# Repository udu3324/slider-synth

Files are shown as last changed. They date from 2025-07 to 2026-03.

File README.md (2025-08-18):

# Slider Synth



A synth that uses a linear touch sensor with a force sensor underneath to create cool sounds. It is inspired by the modulin by wintergatan. Powered by the esp32-s3 and mozzi library.

## Purpose

I built this pcb to make my diy setup more professional. I originally hooked everything up with an arduino but was really hard to cary around without dropping the breadboard or unplugging something. This design leaves it hot pluggable as well as super professional and more polished. 

## Schematic

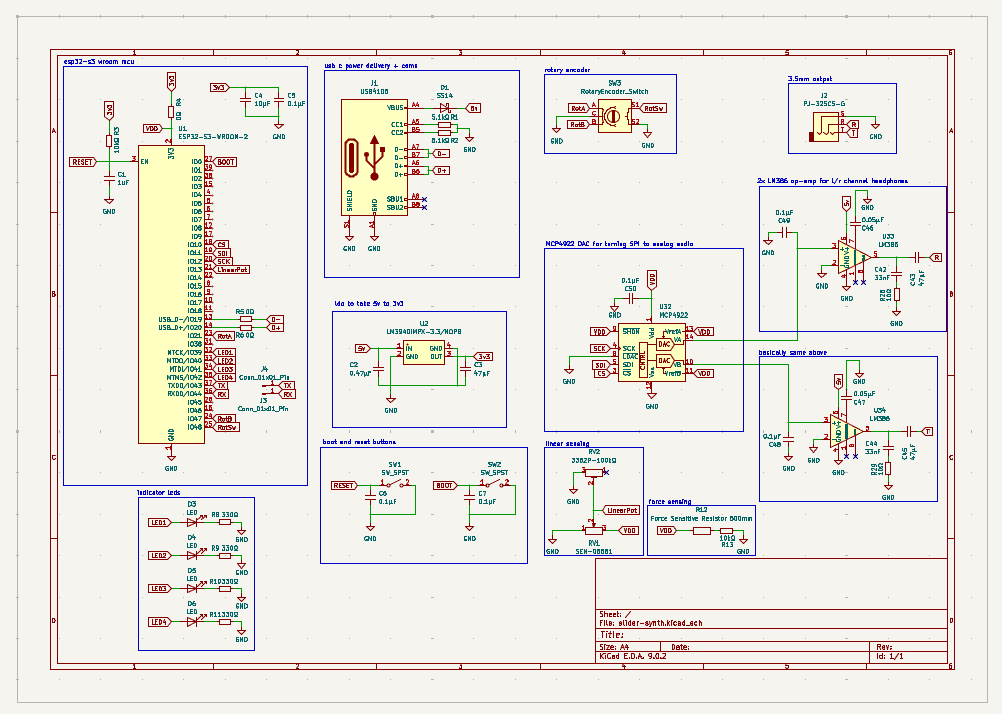
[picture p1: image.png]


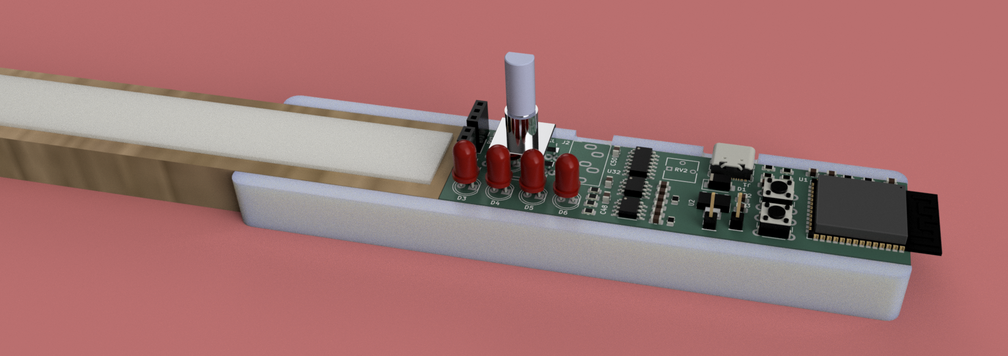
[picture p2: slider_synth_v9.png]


## Additional Notes

[rotary encoder model](https://github.com/KiCad/kicad-packages3D/issues/547)

[sot-223 model](https://grabcad.com/library/discrete-smd-1/details?folder_id=1300113)

## BOM

I am supplying my own esp32-s3, rotary encoder, buttons, leds, and some other stuff that would cause the price to spike up to $30

I also have the linear softpot potentiometer, force sensitive resistor, and plywood strip on hand. **They total about $50** (plywood was scrap/free)

**Before fabricating the pcb, make sure the traces for the FSR is going to IO4 and not IO38!!!**

| Price  | Part Number | Type | LCSC Part | Owner | Designators | Qty | Manufacturer |
|:---|:---|:---|:---|:---|:---|---:|:---|
| $0.02  | CL21A106KAYNNNE | Basic | C15850 | System | C4 | 2 | JLCPCB |
| $0.17  | CL21A476MQYNNNE | Basic | C16780 | System | C3,C43,C45 | 6 | JLCPCB |
| $0.03  | SS14 | Basic | C2480 | System | D1 | 2 | JLCPCB |
| $0.02  | CL21B105KBFNNNE | Basic | C28323 | System | C1 | 2 | JLCPCB |
| $2.11  | LM3940IMPX-3.3/NOPB | Extended | C544820 | System | U2 | 2 | JLCPCB |
| $0.05  | CC0805KRX7R9BB104 | Basic | C49678 | System | C48,C49,C5,C50,C6,C7 | 12 | JLCPCB |
| $0.37  | LM386 | Extended | C5157706 | System | U33,U34 | 4 | JLCPCB |
| $0.03  | CL21B474KBFNNNE | Basic | C13967 | System | C2 | 2 | JLCPCB |
| $0.01  | 0805W8F0000T5E | Basic | C17477 | System | R4,R5,R6 | 6 | JLCPCB |
| $5.35  | MCP4922-E/SL | Extended | C39851 | System | U32 | 2 | JLCPCB |
| $0.01  | 0805W8F1002T5E | Basic | C17414 | System | R13,R3 | 4 | JLCPCB |
| $0.01  | 0805W8F100JT5E | Basic | C17415 | System | R28,R29 | 4 | JLCPCB |
| $2.24  | USB4105-GF-A-120 | Extended | C5184243 | System | J1 | 2 | JLCPCB |
| $0.03  | 0805B333K500NT | Basic | C1739 | System | C42,C44 | 4 | JLCPCB |
| $0.01  | 0805W8F3300T5E | Basic | C17630 | System | R10,R11,R8,R9 | 8 | JLCPCB |
| $0.05  | CL21B473KBCNNNC | Basic | C53134 | Customer | C46,C47 | 4 | JLCPCB |
| $0.01  | 0805W8F5101T5E | Basic | C27834 | System | R1,R2 | 4 | JLCPCB |
| $23.28 | **Total Part Price** | | | | | | |
| | | | | | | | |
| $37.24 | Merchandise Total | | | | | | |
| $26.56 | Shipping Estimate | | | | | | |
| $5.27  | Sales Tax | | | | | | |
| $20.49 | Customs duties & taxes | | | | | | |
| $89.56 | **Grand Total** | | | | | | |

Actual total would be around ~$150 USD including my own components sourced.

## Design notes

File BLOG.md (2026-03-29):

# Post Fabrication Results and Testing

After soldering everything and writing firmware to the slider-synth, there were a couple issues that lowered its quality in general.

At first, one of the sensors did not work at all because I accidentally used a gpio that didn't support analog input. I solved this by soldering a jumper wire which sticks out a little bit, but could easily be fixed for a second round of pcbs.         
           

The audio output kind of sucks. Although it does give a nice harsh analog sound, it is really irritating and no code can fix it due to the passives/ics I used for audio out. I could definitely retry a better design.          
   
     

Plus, i was a little confused and the library i use for digital signal processing (mozzi) specified something else different for my audio. I was trying to implement its [hi-fi audio](https://sensorium.github.io/Mozzi/learn/output/) but accidentally muted the right channel making it a mono output

The PCB also lacks some real mounting holes for more professional case/mounts, and the press fit design sometimes fails due to force from the controls


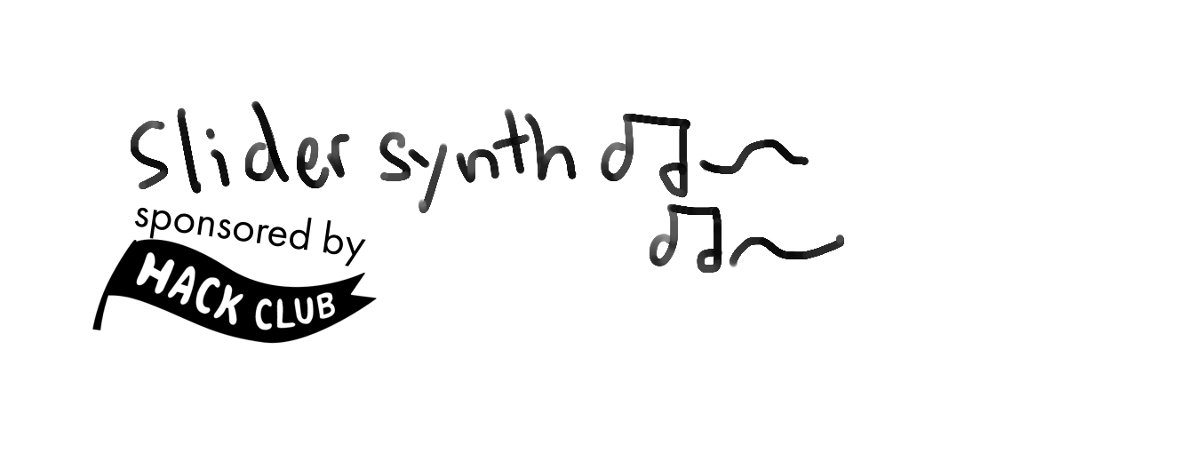
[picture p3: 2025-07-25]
assets/slider-synth-Edge_Cuts.png

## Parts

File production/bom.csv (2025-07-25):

Designator | Footprint | Quantity | Value | LCSC Part #
C1 | 0805 | 1 | 1uF
C2 | 0805 | 1 | 0.47μF
C3, C43, C45 | 0805 | 3 | 47μF
C4 | 0805 | 1 | 10μF
C42, C44 | 0805 | 2 | 33nF
C46, C47 | 0805 | 2 | 0.05μF
C48, C49, C5, C50, C6, C7 | 0805 | 6 | 0.1μF
D1 | D_SMA | 1 | SS14
D3, D4, D5, D6 | LED_D5.0mm | 4 | LED
J1 | USB_C_Receptacle_GCT_USB4105-xx-A_16P_TopMnt_Horizontal | 1 | USB4105
J2 | Jack_3.5mm_CUI_SJ1-3535NG_Horizontal | 1 | PJ-325C5-G | C692438
J3, J4 | PinHeader_1x01_P2.54mm_Vertical | 2 | Conn_01x01_Pin
R1, R2 | 0805 | 2 | 5.1kΩ
R10, R11, R8, R9 | 0805 | 4 | 330Ω
R12 | PinSocket_1x02_P2.54mm_Vertical | 1 | Force Sensitive Resistor 500mm
R13, R3 | 0805 | 2 | 10kΩ
R28, R29 | 0805 | 2 | 10Ω
R4, R5, R6 | 0805 | 3 | 0Ω
RV1 | PinSocket_1x03_P2.54mm_Vertical | 1 | SEN-08681
RV2 | POT_3362P | 1 | 3362P-100kΩ
SW1, SW2 | SW_PUSH_6mm | 2 | SW_SPST
SW3 | RotaryEncoder_Alps_EC11E-Switch_Vertical_H20mm | 1 | RotaryEncoder_Switch
U1 | ESP32-S3-WROOM-2 | 1 | ESP32-S3-WROOM-2
U2 | SOT-223-4_L6.5-W3.5-P2.30-LS7.0-BR | 1 | LM3940IMPX-3.3/NOPB | C544820
U32 | SOIC-14_3.9x8.7mm_P1.27mm | 1 | MCP4922
U33, U34 | SOIC-8_3.9x4.9mm_P1.27mm | 2 | LM386

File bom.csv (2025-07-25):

Part Number | Type | LCSC Part | Owner | Designators | Qty | Manufacturer | Price
CL21A106KAYNNNE | Basic | C15850 | System | C4 | 2 | JLCPCB | $0.02
CL21A476MQYNNNE | Basic | C16780 | System | C3,C43,C45 | 6 | JLCPCB | $0.17
SS14 | Basic | C2480 | System | D1 | 2 | JLCPCB | $0.03
CL21B105KBFNNNE | Basic | C28323 | System | C1 | 2 | JLCPCB | $0.02
LM3940IMPX-3.3/NOPB | Extended | C544820 | System | U2 | 2 | JLCPCB | $2.11
CC0805KRX7R9BB104 | Basic | C49678 | System | C48,C49,C5,C50,C6,C7 | 12 | JLCPCB | $0.05
LM386 | Extended | C5157706 | System | U33,U34 | 4 | JLCPCB | $0.37
CL21B474KBFNNNE | Basic | C13967 | System | C2 | 2 | JLCPCB | $0.03
0805W8F0000T5E | Basic | C17477 | System | R4,R5,R6 | 6 | JLCPCB | $0.01
MCP4922-E/SL | Extended | C39851 | System | U32 | 2 | JLCPCB | $5.35
0805W8F1002T5E | Basic | C17414 | System | R13,R3 | 4 | JLCPCB | $0.01
0805W8F100JT5E | Basic | C17415 | System | R28,R29 | 4 | JLCPCB | $0.01
USB4105-GF-A-120 | Extended | C5184243 | System | J1 | 2 | JLCPCB | $2.24
0805B333K500NT | Basic | C1739 | System | C42,C44 | 4 | JLCPCB | $0.03
0805W8F3300T5E | Basic | C17630 | System | R10,R11,R8,R9 | 8 | JLCPCB | $0.01
CL21B473KBCNNNC | Basic | C53134 | Customer | C46,C47 | 4 | JLCPCB | $0.05
0805W8F5101T5E | Basic | C27834 | System | R1,R2 | 4 | JLCPCB | $0.01

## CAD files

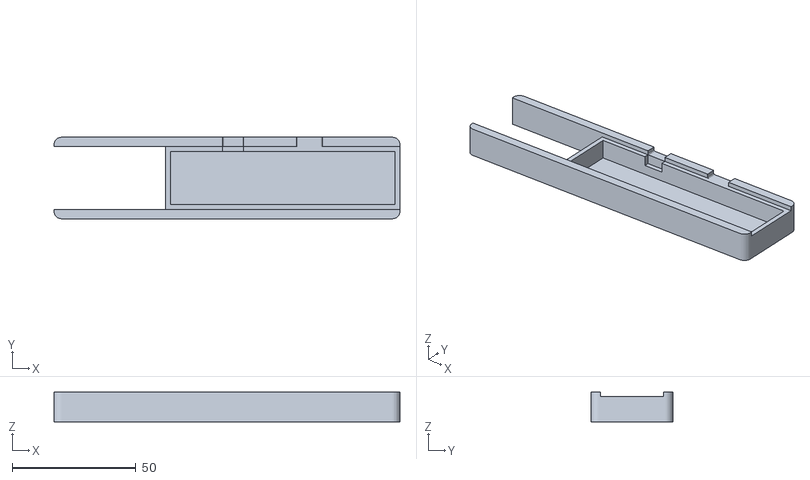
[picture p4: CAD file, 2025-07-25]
cad/Case.stl
140.0 x 33.0 x 12.0

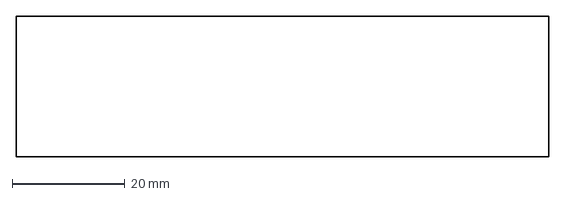
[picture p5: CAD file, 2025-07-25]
pcb/pcb edge cut.dxf
94.5 x 25.0 mm

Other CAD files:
cad/slider synth v7.f3d

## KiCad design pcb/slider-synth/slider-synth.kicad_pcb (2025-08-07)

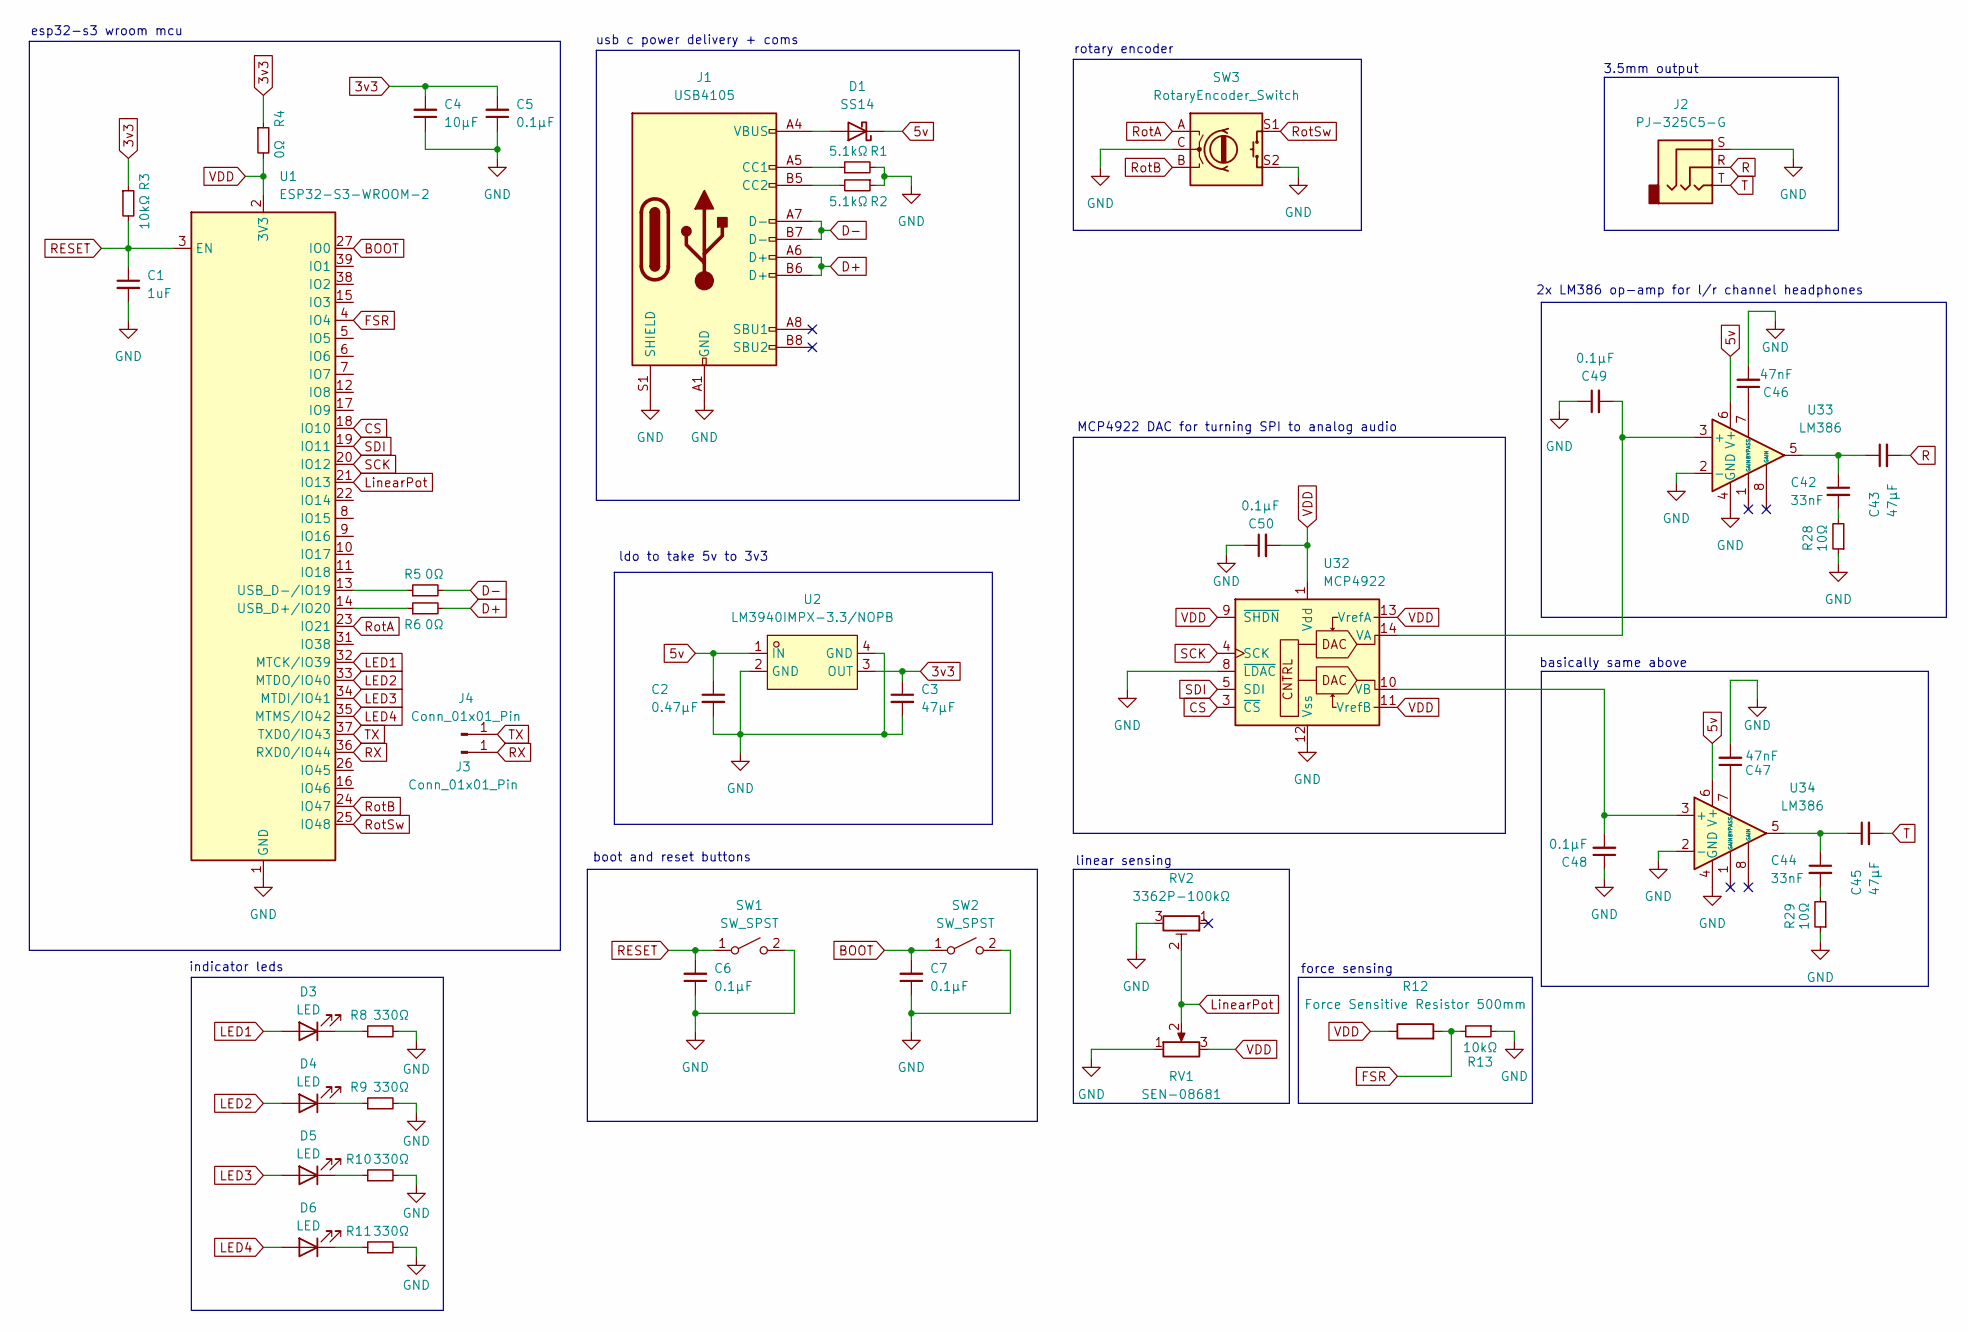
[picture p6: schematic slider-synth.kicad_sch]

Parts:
C1: 1uF; C_0805_2012Metric
C2: 0.47μF; C_0805_2012Metric
C3, C43, C45: 47μF; C_0805_2012Metric
C4: 10μF; C_0805_2012Metric
C5, C6, C7, C48, C49, C50: 0.1μF; C_0805_2012Metric
C42, C44: 33nF; C_0805_2012Metric
C46, C47: 47nF; C_0805_2012Metric
D1: SS14; D_SMA
D3, D4, D5, D6: LED; LED_D5.0mm
J1: USB4105; USB_C_Receptacle_GCT_USB4105-xx-A_16P_TopMnt_Horizontal
J2: PJ-325C5-G; Jack_3.5mm_CUI_SJ1-3535NG_Horizontal; LCSC C692438
J3, J4: Conn_01x01_Pin; PinHeader_1x01_P2.54mm_Vertical
R1, R2: 5.1kΩ; R_0805_2012Metric
R3, R13: 10kΩ; R_0805_2012Metric
R4, R5, R6: 0Ω; R_0805_2012Metric
R8, R9, R10, R11: 330Ω; R_0805_2012Metric
R12: Force Sensitive Resistor 500mm; PinSocket_1x02_P2.54mm_Vertical
R28, R29: 10Ω; R_0805_2012Metric
RV1: SEN-08681; PinSocket_1x03_P2.54mm_Vertical
RV2: 3362P-100kΩ; POT_3362P
SW1, SW2: SW_SPST; SW_PUSH_6mm
SW3: RotaryEncoder_Switch; RotaryEncoder_Alps_EC11E-Switch_Vertical_H20mm
U1: ESP32-S3-WROOM-2
U2: LM3940IMPX-3.3/NOPB; SOT-223-4_L6.5-W3.5-P2.30-LS7.0-BR; LCSC Part C544820
U32: MCP4922; SOIC-14_3.9x8.7mm_P1.27mm
U33, U34: LM386; SOIC-8_3.9x4.9mm_P1.27mm

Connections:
3v3: C3.1, C4.2, C5.2, R3.1, R4.1, U2.3 (OUT)
5v: C2.1, D1.1 (K), U2.1 (IN), U33.6 (V+), U34.6 (V+)
BOOT: C7.2, SW2.1 (A), U1.27 (IO0)
CS: U1.18 (IO10), U32.3 (~CS)
D+: J1.A6 (D+), J1.B6 (D+), R6.2
D-: J1.A7 (D-), J1.B7 (D-), R5.2
FSR: R12.2, R13.2, U1.4 (IO4)
GND: C1.2, C2.2, C3.2, C4.1, C5.1, C6.1, C7.1, C46.2, C47.2, C48.1, C49.1, C50.1, J1.A1 (GND), J1.A12 (GND), J1.B1 (GND), J1.B12 (GND), J1.S1 (SHIELD), J2.S, R1.2, R2.1, R8.2, R9.2, R10.2, R11.2, R13.1, R28.1, R29.1, RV1.1, RV2.3, SW1.2 (B), SW2.2 (B), SW3.C, SW3.S2, U1.1 (GND), U1.40 (GND), U1.41 (GND), U2.2 (GND), U2.4 (GND), U32.8 (~LDAC), U32.12 (Vss), U33.2 (-), U33.4 (GND), U34.2 (-), U34.4 (GND)
LED1: D3.2 (A), U1.32 (MTCK/IO39)
LED2: D4.2 (A), U1.33 (MTDO/IO40)
LED3: D5.2 (A), U1.34 (MTDI/IO41)
LED4: D6.2 (A), U1.35 (MTMS/IO42)
LinearPot: RV1.2, RV2.2, U1.21 (IO13)
unnamed: C42.1, C43.1, U33.5
unnamed: C42.2, R28.2
unnamed: C44.1, C45.1, U34.5
unnamed: C44.2, R29.2
unnamed: D1.2 (A), J1.A4 (VBUS), J1.A9 (VBUS), J1.B4 (VBUS), J1.B9 (VBUS)
unnamed: D3.1 (K), R8.1
unnamed: D4.1 (K), R9.1
unnamed: D5.1 (K), R10.1
unnamed: D6.1 (K), R11.1
unnamed: J1.A5 (CC1), R1.1
unnamed: J1.B5 (CC2), R2.2
unnamed: R6.1, U1.14 (USB_D+/IO20)
unnamed: R5.1, U1.13 (USB_D-/IO19)
unnamed: C49.2, U32.14 (VA), U33.3 (+)
unnamed: C48.2, U32.10 (VB), U34.3 (+)
unnamed: C46.1, U33.7 (BYPASS)
unnamed: C47.1, U34.7 (BYPASS)
R: C43.2, J2.R
RESET: C1.1, C6.2, R3.2, SW1.1 (A), U1.3 (EN)
RX: J3.1, U1.36 (RXD0/IO44)
RotA: SW3.A, U1.23 (IO21)
RotB: SW3.B, U1.24 (IO47)
RotSw: SW3.S1, U1.25 (IO48)
SCK: U1.20 (IO12), U32.4 (SCK)
SDI: U1.19 (IO11), U32.5 (SDI)
T: C45.2, J2.T
TX: J4.1, U1.37 (TXD0/IO43)
VDD: C50.2, R4.2, R12.1, RV1.3, U1.2 (3V3), U32.1 (Vdd), U32.9 (~SHDN), U32.11 (VrefB), U32.13 (VrefA)

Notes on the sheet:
esp32-s3 wroom mcu
MCP4922 DAC for turning SPI to analog audio
3.5mm output
force sensing
basically same above
rotary encoder
usb c power delivery + coms
ldo to take 5v to 3v3
2x LM386 op-amp for l/r channel headphones
boot and reset buttons
indicator leds
linear sensing

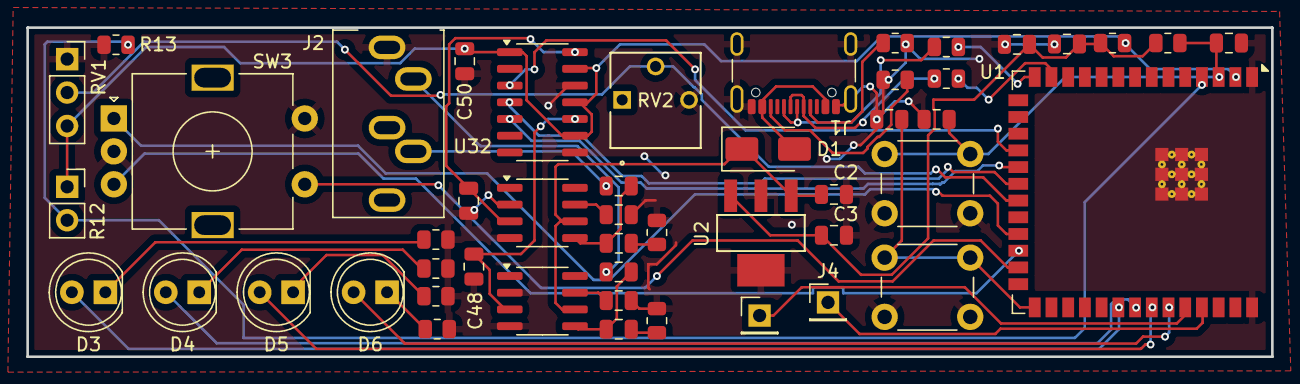
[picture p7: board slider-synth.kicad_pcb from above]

Board: 2 copper layers, 94.6 x 25.0 mm, 49 parts (0 on the bottom side), 41 nets.

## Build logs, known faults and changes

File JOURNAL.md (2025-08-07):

---
title: "slider synth"
author: "@Danny"
description: "A esp32 based synth that uses a touch pot and fsr."
created_at: "2025-07-23"
---

**Total time take: 15 hours**

# June 23rd: Planning + Schematic



I used some of my own references as well as these ones below. I was able to setup a lot of essential features like usb c flashing, 5v to 3v3, uart, and boot/reset buttons.
* [devkit schematics](https://dl.espressif.com/dl/schematics/SCH_ESP32-S3-DevKitC-1_V1.1_20220413.pdf)
* [esp32-s3-wroom datasheet](https://www.espressif.com/sites/default/files/documentation/esp32-s3-wroom-1_wroom-1u_datasheet_en.pdf)
* [user guide](https://docs.espressif.com/projects/esp-dev-kits/en/latest/esp32s3/esp32-s3-devkitc-1/user_guide_v1.1.html)

**Total time spent: ~4 hours**

# June 24th: Adding more features



I finished all of the audio circuit above and added more features like led indicators and a rotary encoder for extra control.



**Total time spent: ~6 hours**

# June 25th: Placement, Routing, CAD, and everything else



For placement, I had a solid plan of selecting an entire box/feature in my schematic and seperating that to then place.

After everything was placed, I can finally route and rotate any components if needed for better routing.



I made a simple case that would press fit onto my plywood strip and pcb. I wanted it to be flush with the thickness of the plywood to not add any extra height.

**Total time spent: ~5 hours**

# MILESTONE: MY PROJECT WAS APPROVED!!!!

Time to wait for the grant and everything to be shipped.

**Total time spent: ~0 hours**

# August 4th: PCB Assembly



My pcbs arrived! I chose to not to include some parts as it would cost more to assemble. I have some on hand already, like the esp32-s3-wroom.



I also did not order a stencil, so I had to manually apply and shape the solder paste to each pad. It was okay.

**Total time spent: ~4 hours**

# August 5th: Finished Assembly, now Debugging





I am so glad I connected my UART to these headers for debugging on my oscilliscope. For some reason, I can't get platformio to read any serial.



I am so stupid. I did not check if the pinout i chose for my force sensitive resistor supported adc. (IO38) I had to solder a jumper wire to fix this issue.

Moving onto the code part, something is not right. I am using mozzi which is a dsp library for synths. For some reason, it either outputs nothing or strange frequencies. Hopefully its not my schematic that is wrong.

**Total time spent: ~6 hours**

# August 6th: Finished!!!



I found out the original reason why my synth sounded strange. It was because i was calculating my hz wrong for my scale, as the numbers were very large/wrong.

I put four leds and a encoder with a button to cycle through modes that modify the synth's sound.

After making sure everything was programmed right with little bugs left, it sounded neat and has tons of possibilities now.

**Total time spent: ~4 hours**

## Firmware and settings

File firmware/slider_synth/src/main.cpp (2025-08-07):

#include "MozziConfigValues.h"  // for named option values

#define MOZZI_AUDIO_MODE MOZZI_OUTPUT_EXTERNAL_TIMED
#define MOZZI_AUDIO_BITS 24
#define MOZZI_CONTROL_RATE 256 // Hz, powers of 2 are most reliable

#include <Mozzi.h>
#include <Oscil.h>
#include <tables/sin2048_int8.h> // table for Oscils to play

#include <SPI.h>
#include <DAC_MCP49xx.h>  // https://github.com/tomcombriat/DAC_MCP49XX 
// which is an adapted fork from https://github.com/exscape/electronics/tree/master/Arduino/Libraries/DAC_MCP49xx  (Thomas Backman)
#include <ESP32Encoder.h>
#include <Ticker.h>

#define Linear_Pot_Pin 13 // Linear Potentiometer
#define FSR_Pin 4 // Force Sensitive Resistor

#define LED0_Pin 39
#define LED1_Pin 40
#define LED2_Pin 41
#define LED3_Pin 42

#define TX_Pin 43
#define RX_Pin 44

#define Rotary_A_Pin 21
#define Rotary_B_Pin 47
#define Rotary_Button_Pin 48

#define SPI_SCK   12  // SCK (Clock)
#define SPI_MOSI  11  // SDI (MOSI)
#define SPI_MISO  9   // SDO (MISO) UNUSED, NOT ON THE MCP4922
// External audio output parameters and DAC declaration
#define SS_PIN 10  // if you are on AVR and using PortWrite you need still need to put the pin you are actually using: 7 on Uno, 38 on Mega
#define BITS_PER_CHANNEL 12  // each channel of the DAC is outputting 12 bits

const int fsr_vel_start = 18000;
const int fsr_velocity_limit = 56688;

int starting_octave = 3; //cant be less than 0
const int scale = 3; //scale of octaves playable

int pitch; //27.5hz-4186hz
int velocity; //0-127

const float base_freq = 32.703; // C1
float hz_map_low;
float hz_map_high;

float depth = 0.02;

//not me
const float depth_min = 0.0;
const float depth_max = 0.2;
const float depth_step = 0.01;

float vibrato_speed = 6.5;
const float vibrato_speed_min = 1.0;
const float vibrato_speed_max = 15.0;
const float vibrato_speed_step = 0.5;

float filter_cutoff = 1.0;
const float filter_cutoff_min = 0.1;
const float filter_cutoff_max = 2.0;
const float filter_cutoff_step = 0.1;
//not me above

int mode = 0;
int changing_to = 0;
bool changing_mode = false;

// Synthesis part
Oscil <SIN2048_NUM_CELLS, MOZZI_AUDIO_RATE> aSin(SIN2048_DATA);
Oscil <2048, MOZZI_CONTROL_RATE> kVib(SIN2048_DATA);

DAC_MCP49xx dac(DAC_MCP49xx::MCP4922, SS_PIN);

ESP32Encoder encoder;

int linear_val;
int force_val;
int encoder_count = 0;
bool slow_down = false;

void ledModeFlash();

Ticker ledModeFlashTimer(ledModeFlash, 100);

void ledModeFlash() {

  digitalWrite(LED0_Pin, LOW);
  digitalWrite(LED1_Pin, LOW);
  digitalWrite(LED2_Pin, LOW);
  digitalWrite(LED3_Pin, LOW);

  if (changing_mode) {
    switch (changing_to) {
      case 0:
        digitalWrite(LED0_Pin, !digitalRead(LED0_Pin));
        break;
      case 1:
        digitalWrite(LED1_Pin, !digitalRead(LED1_Pin));
        break;
      case 2:
        digitalWrite(LED2_Pin, !digitalRead(LED2_Pin));
        break;
      case 3:
        digitalWrite(LED3_Pin, !digitalRead(LED3_Pin));
        break;
    }
  } else {
    switch (mode) {
      case 0:
        digitalWrite(LED0_Pin, HIGH);
        break;
      case 1:
        digitalWrite(LED1_Pin, HIGH);
        break;
      case 2:
        digitalWrite(LED2_Pin, HIGH);
        break;
      case 3:
        digitalWrite(LED3_Pin, HIGH);
        break;
    }
  }
}

void buttonSlowDown();

Ticker slowDownTimer(buttonSlowDown, 1000);

void buttonSlowDown() {
  slow_down = false;
}

void generateHz() {
  hz_map_low = base_freq * pow(2, starting_octave - 1);
  hz_map_high = hz_map_low * pow(2, scale);
}

void octaveUp() {
  if (starting_octave >= 8) return;

  starting_octave++;
  generateHz();
}

void octaveDown() {
  if (starting_octave <= -2) return;

  starting_octave--;
  generateHz();
}

void vibratoUp() {
  if (depth >= depth_max) return;
  
  depth += depth_step;
  if (depth > depth_max) depth = depth_max;
}

void vibratoDown() {
  if (depth <= depth_min) return;
  
  depth -= depth_step;
  if (depth < depth_min) depth = depth_min;
}

void vibratoSpeedUp() {
  if (vibrato_speed >= vibrato_speed_max) return;
  
  vibrato_speed += vibrato_speed_step;
  if (vibrato_speed > vibrato_speed_max) vibrato_speed = vibrato_speed_max;
  
  kVib.setFreq(vibrato_speed);
}

void vibratoSpeedDown() {
  if (vibrato_speed <= vibrato_speed_min) return;
  
  vibrato_speed -= vibrato_speed_step;
  if (vibrato_speed < vibrato_speed_min) vibrato_speed = vibrato_speed_min;
  
  kVib.setFreq(vibrato_speed);
}

void filterUp() {
  if (filter_cutoff >= filter_cutoff_max) return;
  
  filter_cutoff += filter_cutoff_step;
  if (filter_cutoff > filter_cutoff_max) filter_cutoff = filter_cutoff_max;
}

void filterDown() {
  if (filter_cutoff <= filter_cutoff_min) return;
  
  filter_cutoff -= filter_cutoff_step;
  if (filter_cutoff < filter_cutoff_min) filter_cutoff = filter_cutoff_min;
}

void runEncoderModeUp() {
  switch (mode) {
    case 0:
      octaveUp();
      break;
    case 1:
      vibratoUp();
      break;
    case 2:
      vibratoSpeedUp();
      break;
    case 3:
      filterUp();
      break;
  }
}

void runEncoderModeDown() {
  switch (mode) {
    case 0:
      octaveDown();
      break;
    case 1:
      vibratoDown();
      break;
    case 2:
      vibratoSpeedDown();
      break;
    case 3:
      filterDown();
      break;
  }
}

void audioOutput(const AudioOutput f) // f is a structure containing both channels
{

  int out = MOZZI_AUDIO_BIAS + f.l();

  unsigned short lowBits = (unsigned short) out;  //
  unsigned short highBits =  out >> BITS_PER_CHANNEL;

  dac.output2(highBits, lowBits);  // outputs the two channels in one call.
}

void setup() {
  // serial for uart
  Serial.begin(115200, SERIAL_8N1, RX, TX);

  Serial.println("udu3324 was here!!");

  // Set custom SPI pins
  SPI.begin(SPI_SCK, SPI_MISO, SPI_MOSI);

  dac.init();   // start SPI communications
  //dac.setPortWrite(true);  //comment this line if you do not want to use PortWrite (for non-AVR platforms)
  
  //calculate the starting hz
  generateHz();

  //vibrato setup
  kVib.setFreq(vibrato_speed);

  pinMode(LED0_Pin, OUTPUT);
  pinMode(LED1_Pin, OUTPUT);
  pinMode(LED2_Pin, OUTPUT);
  pinMode(LED3_Pin, OUTPUT);

  pinMode(Rotary_A_Pin, INPUT_PULLUP);
  pinMode(Rotary_B_Pin, INPUT_PULLUP);

  pinMode(Rotary_Button_Pin, INPUT_PULLUP);

  encoder.attachSingleEdge(Rotary_A_Pin, Rotary_B_Pin);
  encoder.setCount(0);

  startMozzi();
  Serial.println("on!!!!!!!!");

  ledModeFlashTimer.start();
  slowDownTimer.start();

}

// Carry enveloppes
float filter_memory = 0.0; // For simple low-pass filter

void updateControl() {
  Serial.println("it is looping!!!");

  if (digitalRead(Rotary_Button_Pin) == LOW && !slow_down) {
    changing_mode = !changing_mode;

    if (!changing_mode) {
      mode = changing_to;
    }

    slow_down = true;
  }

  if (encoder.getCount() > encoder_count) {
    if (changing_mode && changing_to < 3 ) {
      changing_to = changing_to + 1;
    } else {
      runEncoderModeUp();
    }
  } else if (encoder.getCount() < encoder_count) {
    if (changing_mode && changing_to > 0 ) {
      changing_to = changing_to - 1;
    } else {
      runEncoderModeDown();
    }
  }

  encoder_count = encoder.getCount();

  ledModeFlashTimer.update();
  slowDownTimer.update();

  linear_val = mozziAnalogRead16(Linear_Pot_Pin);
  force_val = mozziAnalogRead16(FSR_Pin);

  //map to freq and vel
  pitch = map(linear_val, 0, 65536, hz_map_low, hz_map_high);
  velocity = map(force_val, fsr_vel_start, fsr_velocity_limit, 0, 20);

  //hard limits
  if ((linear_val == 0)) pitch = 0; //stop mapping of zero
  if (velocity > 127) velocity = 127; //stop higher mappings

  //stop negative numbers for some reason
  if (velocity < 0) velocity = 0;

  float vibrato = (velocity * depth) * kVib.next();

  Serial.print("p = \t");
  Serial.print(pitch);
  Serial.print("\t v = ");
  Serial.println(velocity);

  if (linear_val > 0) {
    aSin.setFreq(pitch + vibrato);
  } else {
    aSin.setFreq(0);
  }
}

AudioOutput updateAudio() {
  int32_t sample = (int32_t)aSin.next();
  
  // Apply simple low-pass filter (cutoff controlled by filter_cutoff)
  float alpha = filter_cutoff / (filter_cutoff + 1.0);
  filter_memory = alpha * sample + (1.0 - alpha) * filter_memory;
  
  int32_t filtered_sample = (int32_t)filter_memory;
  
  return MonoOutput::fromNBit(24, filtered_sample); // specify that the audio we are sending here is 24 bits.
}

void loop() {  
  audioHook();
}

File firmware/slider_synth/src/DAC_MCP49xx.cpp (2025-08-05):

/*
Tweak of the following library for use with STM32 and other non_AVR platforms.
T. Combriat

 * Microchip MCP4901 / MCP4911 / MCP4921 / MCP4902 / MCP4912 / MCP4922 8/10/12-bit DAC driver
 * Thomas Backman, 2012-07 (made a proper library 2011-07-30, 3 weeks after initial)
 * serenity@exscape.org
 * Support for MCP49x2 (MCP4902, MCP4912, MCP4922) added 2012-08-30,
 * with a patch and testing from Jonas Gruska
 
 * Code license: BSD/MIT. Whatever; I *prefer* to be credited,
 * and you're *not* allowed to claim you wrote this from scratch.
 * Apart from that, do whatever you feel like. Commercial projects,
 * code modifications, etc.

 Pins used: 
 * Arduino pin 11 (for Uno; for Mega: 51) to device SDI (pin 4) - fixed pin
 * Arduino pin 13 (for Uno; for Mega: 52) to device SCK (pin 3) - fixed pin
 * Any digital pin to device LDAC (DAC pin 5)  (except with PortWrite, see README)
 * Any digital pin to device CS   (DAC pin 2)  (as above)
 *
 * Other DAC wirings:  
 * Pin 1: VDD, to +5 V
 * Pin 5: LDAC, either to an Arduino pin, or ground to update vout automatically
 * Pin 6: VREF, to +5 V (or some other reference voltage 0 < VREF <= VDD)
 * Pin 7: VSS, to ground
 * Pin 8: vout
 * (Pin 9, for the DFN package only: VSS)

 * Only tested on MCP4901 (8-bit) and MCP4922 (dual 12-bit), but it should work on the others as well.
 * Tested on an Arduino Uno R3.
 */

#include <Arduino.h>
#include <SPI.h>
#include "DAC_MCP49xx.h"

DAC_MCP49xx::DAC_MCP49xx(DAC_MCP49xx::Model _model, int _ss_pin) : bufferVref(false), gain2x(false), port_write(false)
{
  this->ss_pin = _ss_pin;

  /* 
   * MCP49x1 models are single DACs, while MCP49x2 are dual.
   * Apart from that, only the bit width differ between the models.
   */
  switch (_model) {
  case MCP4901:
  case MCP4902:
    bitwidth = 8;
    break;
  case MCP4911:
  case MCP4912:
    bitwidth = 10;
    break;
  case MCP4921:
  case MCP4922:
    bitwidth = 12;
    break;
  default:
    bitwidth = 0;
  }
  
  pinMode(ss_pin, OUTPUT); // Ensure that SS is set to SPI master mode

  digitalWrite(ss_pin, HIGH); // Unselect the device

  }

void DAC_MCP49xx::init()
{
  dac_spi = & SPI;
  dac_spi->begin();
   dac_spi->beginTransaction(SPISettings(2000000000, MSBFIRST, SPI_MODE0));
}

void DAC_MCP49xx::init(SPIClass *_spi)
{
  dac_spi = _spi;
  dac_spi->begin();
   dac_spi->beginTransaction(SPISettings(2000000000, MSBFIRST, SPI_MODE0));
}

void DAC_MCP49xx::setBuffer(boolean _buffer)
{
  this->bufferVref = _buffer;
}

void DAC_MCP49xx::setPortWrite(boolean _port_write)
{
  this->port_write = _port_write; 
}



// Sets the gain. These DACs support 1x and 2x gain.
// vout = x/2^n * gain * VREF, where x = the argument to out(), n = number of DAC bits
// Example: with 1x gain, set(100) on a 8-bit (256-step) DAC would give
// an output voltage of 100/256 * VREF, while a gain of 2x would give
// vout = 100/256 * VREF * 2
boolean DAC_MCP49xx::setGain(int _gain) {
  if (_gain == 1) {
    gain2x = false;
    return true;
  }
  else if (_gain == 2) {
    gain2x = true;
    return true;
  }
  else
    return false; // DAC only supports 1x and 2x
}

// Sets the SPI clock frequency. The final frequency will be the 
// main Arduino clock divided by the divider selected here.
/*
boolean DAC_MCP49xx::setSPIDivider(int _div) {
  switch (_div) {
  case SPI_CLOCK_DIV2:
  case SPI_CLOCK_DIV4:
  case SPI_CLOCK_DIV8:
  case SPI_CLOCK_DIV16:
  case SPI_CLOCK_DIV32:
  case SPI_CLOCK_DIV64:
  case SPI_CLOCK_DIV128:
    spi_divider = _div;
    SPI.setClockDivider(_div);
    return true;
  default:
    return false;
  }
  }*/

// Shuts the DAC down. Shutdown current is about 1/50 (typical) of active mode current.
// My measurements say ~160-180 µA active (unloaded vout), ~3.5 µA shutdown.
// Time to settle on an output value increases from ~4.5 µs to ~10 µs, though (according to the datasheet).
void DAC_MCP49xx::shutdown(void) {
  // Drive chip select low
#ifdef __AVR__
  if (this->port_write)
   PORTD &= ~(1 << 7); // Uno: digital pin 7; Mega: digital pin 38
  //PORTD &= ~(1 << 7);
  else
    digitalWrite(ss_pin, LOW);
#else
  digitalWrite(ss_pin, LOW);
#endif
  
  // Sending all zeroes should work, too, but I'm unsure whether there might be a switching time
  // between buffer and gain modes, so we'll send them so that they have the same value once we
  // exit shutdown.
  unsigned short out = (bufferVref << 14) | ((!(gain2x)) << 13); // gain == 0 means 2x, so we need to invert it
  dac_spi->transfer((out & 0xff00) >> 8);
  dac_spi->transfer(out & 0xff);

  // Return chip select to high
#ifdef __AVR__
  if (this->port_write)
    PORTD |= (1 << 7); // set PORTD pin 7 = arduino pin 7 on UNO, 38 on Mega
    //PORTD |= (1 << 7);
  else
    digitalWrite(ss_pin, HIGH);
#else
  digitalWrite(ss_pin, HIGH);
#endif
}

// Private function.
// Called by the output* set of functions.
void DAC_MCP49xx::_output(unsigned short data, Channel chan) {
  // Truncate the unused bits to fit the 8/10/12 bits the DAC accepts
  if (this->bitwidth == 12)
    data &= 0xfff;
  else if (this->bitwidth == 10)
    data &= 0x3ff;
  else if (this->bitwidth == 8)
    data &= 0xff;

  // Drive chip select low
#ifdef __AVR__
  if (this->port_write)
   PORTD &= ~(1 << 7); // Uno: digital pin 7; Mega: digital pin 38
  //PORTD &= ~(1 << 7);
  else
    digitalWrite(ss_pin, LOW);
#else
  digitalWrite(ss_pin, LOW);
#endif

  // bit 15: 0 for DAC A, 1 for DAC B. (Always 0 for MCP49x1.)
  // bit 14: buffer VREF?
  // bit 13: gain bit; 0 for 1x gain, 1 for 2x (thus we NOT the variable)
  // bit 12: shutdown bit. 1 for active operation
  // bits 11 through 0: data 
  uint16_t out = (chan << 15) | (this->bufferVref << 14) | ((!this->gain2x) << 13) | (1 << 12) | (data << (12 - this->bitwidth));
  
  // Send the command and data bits
  dac_spi->transfer((out & 0xff00) >> 8);
  dac_spi->transfer(out & 0xff);

  // Return chip select to high
#ifdef __AVR__
  if (this->port_write)
    PORTD |= (1 << 7); // set PORTD pin 7 = arduino pin 7 on UNO, 38 on Mega
  //PORTD |= (1 << 7);
  else
    digitalWrite(ss_pin, HIGH);
#else
  digitalWrite(ss_pin, HIGH);
#endif

}

// For MCP49x1
void DAC_MCP49xx::output(unsigned short data) {
  this->_output(data, CHANNEL_A);
}

// For MCP49x2
void DAC_MCP49xx::outputA(unsigned short data) {
  this->_output(data, CHANNEL_A);
}

// For MCP49x2
void DAC_MCP49xx::outputB(unsigned short data) {
  this->_output(data, CHANNEL_B);
}

// MCP49x2 (dual DAC) only.
// Send a set of new values for the DAC to output in a single function call
void DAC_MCP49xx::output2(unsigned short data_A, unsigned short data_B) {
  this->_output(data_A, CHANNEL_A);
  this->_output(data_B, CHANNEL_B);
  
  }

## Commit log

2025-07-24 add pcb
    [slider-synth.kicad_pcb, slider-synth.kicad_sch]
2025-07-25 update schem
    [slider-synth.kicad_pcb, slider-synth.kicad_sch]
2025-07-25 price optimizations
    [bom.csv, designators.csv, positions.csv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]
2025-07-25 add fsr and linear pot
    [slider-synth.kicad_pcb, slider-synth.kicad_sch]
2025-07-25 footprints and routing
    [pcb edge cut.dxf, slider-synth.kicad_pcb, slider-synth.kicad_sch]
2025-07-25 prod files, cad, and cool silkscreen
    [Case.stl, bom.csv, designators.csv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]
2025-07-25 Add bom, readme/journal stuff
    [Case.stl, bom.csv, designators.csv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]
2025-08-05 firmware wip
    [large_fat_32MB.csv]
2025-08-07 move io38 to io4, but did not update prod files
    [slider-synth.kicad_pcb, slider-synth.kicad_sch]
